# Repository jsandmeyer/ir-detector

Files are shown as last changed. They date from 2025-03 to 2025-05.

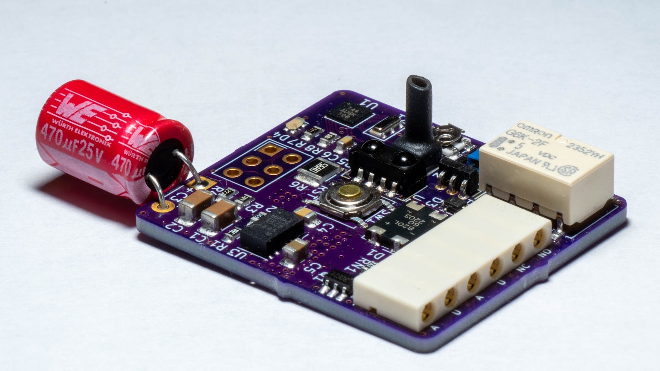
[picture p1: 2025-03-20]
resources/v14_production_model.jpg

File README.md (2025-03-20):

## IR Reflection Detector

This provides resources to help you build an IR detector for use with O-scale model railroad track in order to detect passing trains for operating block signals.

It is designed to be placed beneath the tracks, to allow for the use of more realistic trackside accessories and buildings.

It emits and detects IR at 38KHz (though the frequency can be changed based on part choice).
This prevents background light from affecting function.

The original analog designs utilized a TLC555 CMOS timer.
The timer was unstable through stray capacitance caused by rail operation, and also likely by temperature fluctuations from the power supply.
Small microcontrollers like the ATTINY family are inexpensive, simple to program, and more stable even without an external clock.

The current versions utilize a switching power supply to avoid heat, so the device can be safely placed under track.
The input voltage is 18V RMS AC, which rectifies to 26V DC.
Since only 3-5 volts are needed for the circuit, power dissipation through a linear supply is excessive.

### Design Requirements

1. Must be able to handle 18V RMS AC (or a little more)
2. Must be able to handle rapid shutoff of power
3. Must avoid producing noticeable heat
4. Must fit hidden under track
   1. Shape limits (avoid track supports, power connectors, etc)
   2. Size limits (must not extend past track base, must have a way to feed wires)
   3. Some components must be aligned under a single oblong hole in track base
5. Emitter LED must be shrouded to avoid directly triggering detector
6. Must handle stray capacitance, excessive heat, and some signal interference
7. Must be small to reduce cost, especially when a 4-layer design is used

### Circuit Parts

1. MCU: Responsible for PWM to control the IR emitter, and controlling the relay when a reflection is detected.
2. Switching Power Supply: reduce up to 35VDC input to 3V output for the MCU, IR LED, and relay.
3. IR LED: an emitter running at ~70mA, and 50% duty cycle at 36-56KHz depending on detector part selection.
4. IR Detector: an IC containing both a detector and frequency detection logic, to ensure only correct-frequency light is detected.  36, 38, 40, or 56 KHz.
5. Relay: Controls AC (or DC) current from inputs to a normally-open and normally-closed output.
6. Trimmer: Controls duration of relay after IR is no longer detected.

### Design Versions

Some versions are skipped.
Those were only built on breadboard, or designed and considered non-viable.
Generally, each version is smaller or similar to the previous.

* Version 7: Used TLC556.  Had heat issues from power supply.
* Version 11: Used a switching power supply.  Still had stability issues.
* Version 13: Switched to use an ATTINY84.  Switched to 4-layer board.  Bridge rectifier could not handle rapid shutoff of some transformers.
* Version 14: Larger bridge rectifier.  Production model.  [Image](./resources/v14_production_model.jpg)
* Version 17: Updated layout, components (ATTINY20), and code.  Reduced to 2-layer board.  Manufacturing in process.

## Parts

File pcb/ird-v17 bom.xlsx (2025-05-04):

Ref | Value | SKU | Status | $/1 | $/3 | $/10
C1 | 2.2µF | GCM31CR71H225KA55L |  | $0.33 | $0.99 | $1.98
C2 | 100nF | GCM155R71H104KE02D |  | $0.10 | $0.30 | $0.31
C3 | 1µF | CGA3E1X7R1V105K080AC |  | $0.23 | $0.69 | $1.31
C4 | 10µF | GRM21BR61E106MA73L |  | $0.17 | $0.51 | $0.99
C5 | 100nF | GCM155R71H104KE02D |  | $0.10 | $0.30 | $0.31
C6 | 680µF | 860020575016 |  | $0.61 | $1.83 | $6.01
D1 | -AA+ | CD-HD2006L |  | $0.98 | $2.94 | $7.33
D2 | IR | SFH_4243-Z |  | $0.65 | $1.95 | $4.52
D3 | Diode | 1N4148WS |  | $0.13 | $0.39 | $0.92
D4 | LED | SML-LXFP0603UWW-TR | OPTIONAL | $0.44 | $1.32 | $2.99
J1 | TPI POGO | Atmel 6-pin TPI connector | DNP | $0.00 | $0.00 | $0.00
J2 | Conn 2x6 | 9296006202906 |  | $0.81 | $2.43 | $6.86
K1 | Relay DPDT | G6K-2G-Y-TR DC5 |  | $4.21 | $12.63 | $39.79
Q1 | NPN 10K 10K x2 | MUN5211DW1T1G |  | $0.23 | $0.69 | $1.39
R1 | 10K | RCS040210K0FKED |  | $0.11 | $0.33 | $0.52
R2 | 56R | RCS040256R0FKED |  | $0.12 | $0.36 | $0.58
R3 | 750R | RCS0402750RFKED | OPTIONAL | $0.12 | $0.36 | $0.58
U1 | ATTiny20 | ATTINY20-UUR |  | $1.18 | $3.54 | $11.80
U2 | IR Detector | TSOP75438TT |  | $1.34 | $4.02 | $11.22
U3 | 5V SMPS | TLVM365R1RDNR |  | $2.28 | $6.84 | $16.87
VR1 | 10K | TC42X-2-103E |  | $0.45 | $1.35 | $3.79
PCB | PCB | PCB | PCB | $2.00 | $6.00 | $20.00
Total |  |  |  | $16.59 | $49.77 | $140.07

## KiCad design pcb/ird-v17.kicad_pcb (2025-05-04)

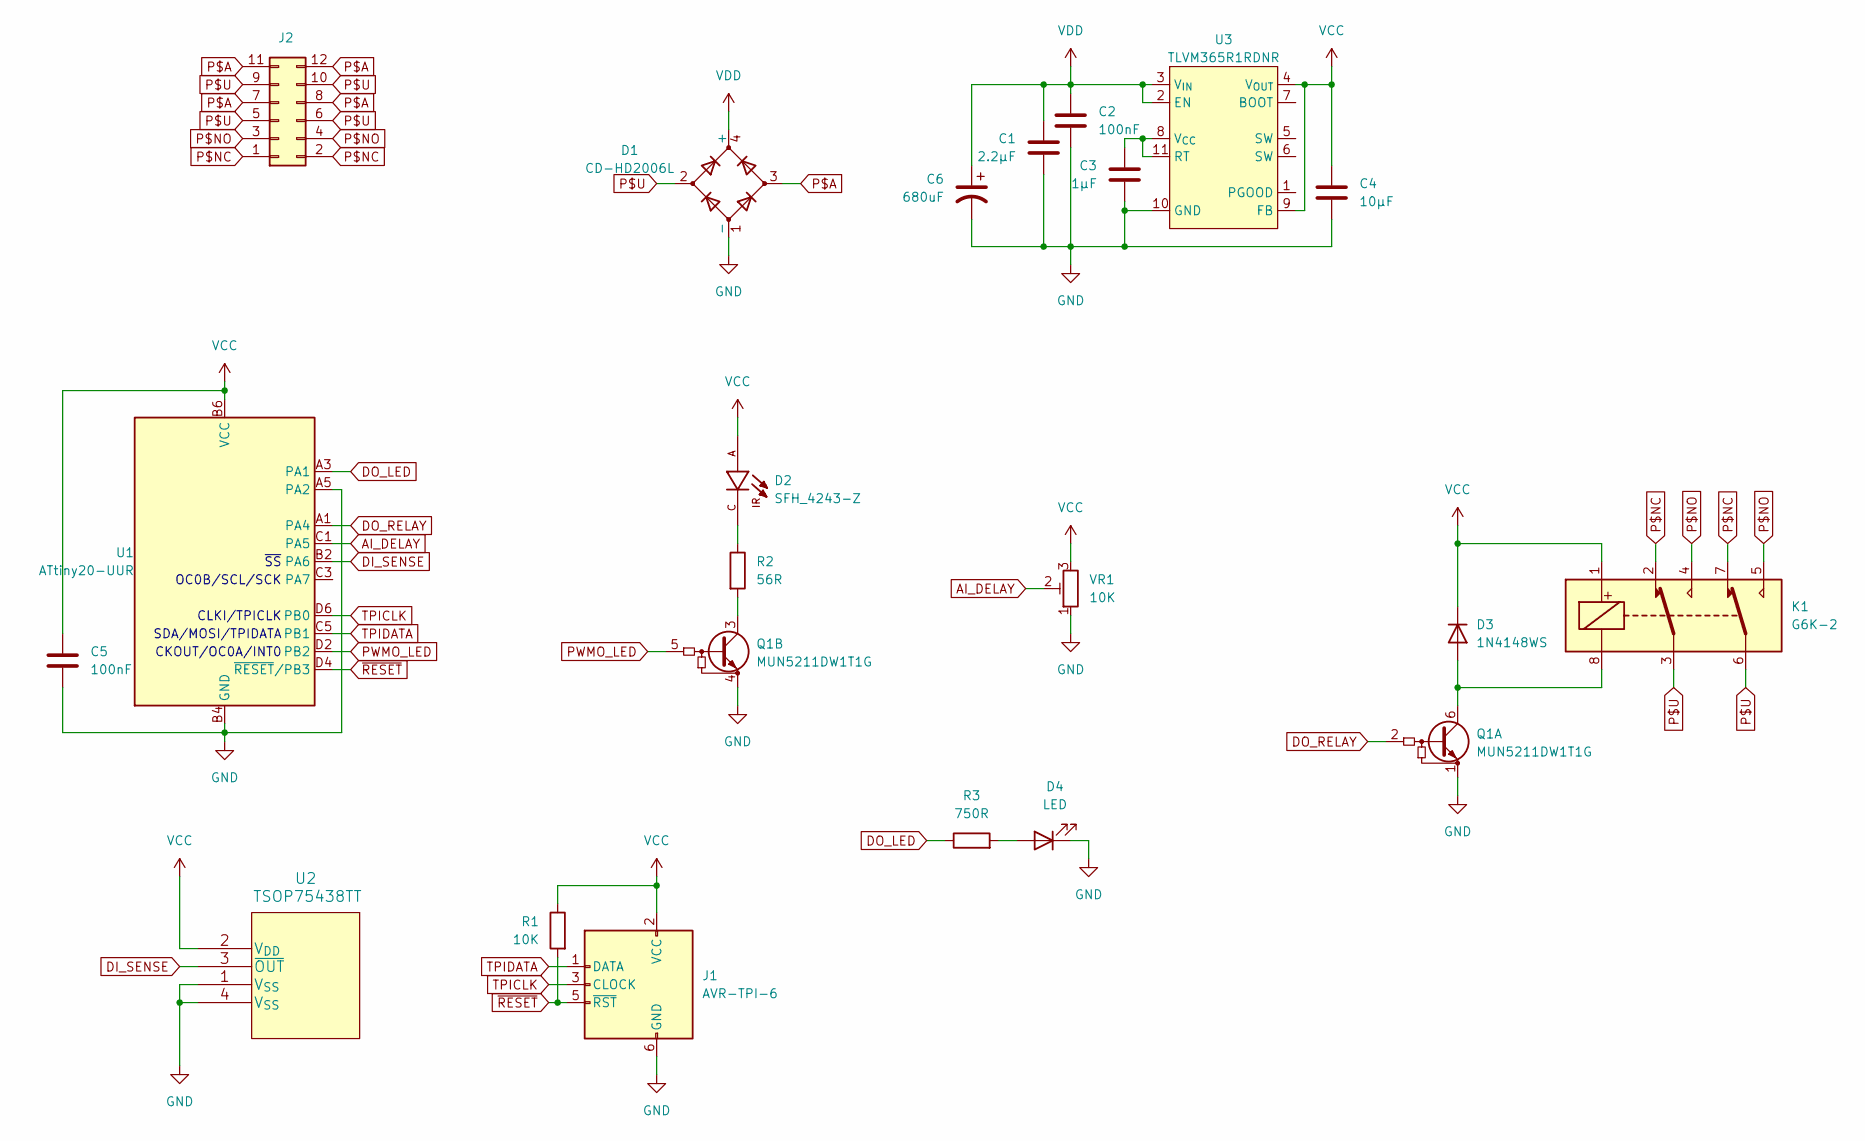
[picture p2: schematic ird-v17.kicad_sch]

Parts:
C1: 2.2µF; C_0805_2012Metric
C2, C5: 100nF; C_0402_1005Metric
C3: 1µF; C_0603_1608Metric
C4: 10µF; C_0805_2012Metric
C6: 680uF; CP_Radial_Long_Sideways_Flip
D1: CD-HD2006L; Diode_Bridge_Bourns_CD-HD2x
D2: SFH_4243-Z; LED_SFH_4243-Z; PARTREV 1.4
D3: 1N4148WS; D_SOD-323
D4: LED; LED_0603_1608Metric
J1: AVR-TPI-6; PinHeader_ISP_POGO
J2: Conn_02x06_Odd_Even; Kyocera_AVX_009296006202906
K1: G6K-2; Relay_DPDT_Omron_G6K-2G-Y
Q1: MUN5211DW1T1G; SOT-363_SC-70-6
R1: 10K; R_0402_1005Metric
R2: 56R; R_0402_1005Metric
R3: 750R; R_0402_1005Metric
U1: ATtiny20-UUR; WLCSP-12_1.403x1.555mm_Layout6x4_P0.4mm_Stagger
U2: TSOP75438TT; TSOP75438WTT
U3: TLVM365R1RDNR; QFN-FCMOD_TI_11C
VR1: 10K; Potentiometer_Bourns_TC42X_Vertical

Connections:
AI_DELAY: U1.C1 (PA5), VR1.2
DI_SENSE: U1.B2 (PA6), U2.3 (~OUT)
DO_LED: R3.1, U1.A3 (PA1)
DO_RELAY: Q1.2 (B1), U1.A1 (PA4)
GND: C1.2, C2.2, C3.2, C4.2, C5.2, C6.2, D1.1 (-), D4.1 (K), J1.6 (GND), Q1.1 (E1), Q1.4 (E2), U1.A5 (PA2), U1.B4 (GND), U2.1 (V_{SS}), U2.4 (V_{SS}), U3.10 (GND), VR1.1
unnamed: D2.C, R2.1
unnamed: D3.2 (A), K1.8, Q1.6 (C1)
unnamed: D4.2 (A), R3.2
unnamed: Q1.3 (C2), R2.2
unnamed: C3.1, U3.8 (V_{CC}), U3.11 (RT)
P$A: D1.3, J2.7, J2.8, J2.11, J2.12
P$NC: J2.1, J2.2, K1.2, K1.7
P$NO: J2.3, J2.4, K1.4, K1.5
P$U: D1.2, J2.5, J2.6, J2.9, J2.10, K1.3, K1.6
PWMO_LED: Q1.5 (B2), U1.D2 (PB2)
TPICLK: J1.3 (CLOCK), U1.D6 (PB0)
TPIDATA: J1.1 (DATA), U1.C5 (PB1)
VCC: C4.1, C5.1, D2.A, D3.1 (K), J1.2 (VCC), K1.1, R1.1, U1.B6 (VCC), U2.2 (V_{DD}), U3.4 (V_{OUT}), U3.9 (FB), VR1.3
VDD: C1.1, C2.1, C6.1, D1.4 (+), U3.2 (EN), U3.3 (V_{IN})
~RESET: J1.5 (~RST), R1.2, U1.D4 (~RESET/PB3)

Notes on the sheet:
CLKI/TPICLK
SDA/MOSI/TPIDATA
CKOUT/OC0A/INT0
~{SS}
OC0B/SCL/SCK

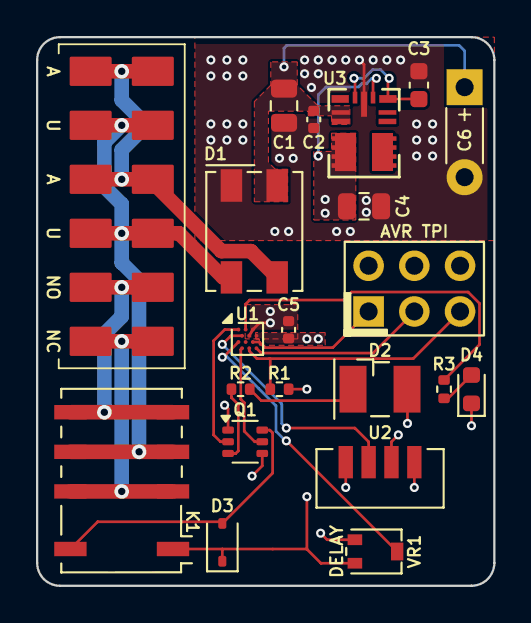
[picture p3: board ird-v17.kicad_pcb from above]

Board: 2 copper layers, 25.4 x 30.5 mm, 21 parts (0 on the bottom side), 20 nets.

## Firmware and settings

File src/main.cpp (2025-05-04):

/*
 * IR Detector V17
 * Send to attiny20 via tpi
 *
 * Created: 2022-07-29 20:26:16
 * Author : John Sandmeyer
 *
 * Optional external defines:
 * DELAY_MAX_S: max delay of relay timer, default 30s
 * IR_HZ: speed of IR LED to match sensor (default 38000L)
 */

#include <avr/io.h>
#include <avr/interrupt.h>
#include <util/delay.h>
#include <avr/sfr_defs.h>
#include "IRManager.h"
#include "RelayManager.h"
#include "ADCManager.h"

static volatile IRManager irManager; // NOSONAR
static volatile RelayManager relayManager; // NOSONAR

int main() {
    // disable prescaler - set CCP to disable configuration change protection
    // enforces a clock source and disables prescaler
    CCP = 0xD8;
    CLKMSR = 0;
    CCP = 0xD8;
    CLKPSR = 0;

    IRManager::configurePWM();
    IRManager::configureInterrupts();

    RelayManager::configurePWM();
    RelayManager::configureInterrupts();
    RelayManager::configureOutputs();

    ADCManager::configureADC();

	// wait 1.5 sec before enabling interrupts
	_delay_ms(1500);
	sei();

    // ReSharper disable once CppDFAEndlessLoop : loop is to keep MCU running while interrupts operate
    while (true) {
		/* loop forever, let interrupts do the work */
	}
}

/**
 * Invoked when something in PORTA is changed
 * Check to see if the state on the pin we care about changed, since it could fire for other reasons
 */
ISR(PCINT0_vect) {
    const auto state = irManager.getIRState();

	if (state == IRManager::State::DETECTED) {
        RelayManager::handleIRDetected();
	} else if (state == IRManager::State::CLEARED) {
	    const auto adcValue = static_cast<unsigned long>(ADCManager::readADC());

#if DEBUG_RELAY_TIMER == 1
	    // in debug mode, IR LED is adjusted based on ADC value for easy testing
	    // use formula HZ = 8MHz / (2 * (1 + OCR0A)) or OCR0A = 4000/KHz - 1
	    // or adcValue = ((4000/KHz) - 1)(1024/255)
	    // adcValue should be between 0 and 1023 (inclusive)
	    // for verification, ADC value 0 -> 4MHz, value 1023 -> 15.686KHz
	    OCR0A = static_cast<uint8_t>(adcValue * 255UL / 1024UL);
	    OCR0B = static_cast<uint8_t>(adcValue * 255UL / 1024UL);
#endif

	    // get the number of ticks based on ADC data, send flag to relay manager
	    const auto ticks = (adcValue * RelayManager::delayMultiplier) / RelayManager::maxADC;
	    relayManager.handleIRCleared(ticks);
	}
}

/**
 * Runs when TIMER1 compare matches
 * Use to decrement relay manager's timer, to turn off the relay eventually
 */
ISR(TIM1_COMPA_vect) {
    relayManager.tick();
}

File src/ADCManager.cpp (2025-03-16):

#include "ADCManager.h"

void ADCManager::configureADC() {
    // Pin A1 has the variable resistor
    DDRA &= ~_BV(adcPin);

    // Right half of ADMUX selects which channel to read, leave left half alone
    ADMUX &= 0xF0;
    ADMUX |= adcChannel; // select channel 1

    // Disable digital input on ADC1
    DIDR0 = _BV(ADC1D);

    // Enable the ADC
    ADCSRA |= _BV(ADEN);
    ADCSRA |= _BV(ADSC);
}

uint16_t ADCManager::readADC() {
    ADMUX &= 0xF0;
    ADMUX |= adcChannel;
    ADCSRA |= _BV(ADSC);

    while (ADCSRA & _BV(ADSC)) {
        /* wait for ADSC to return to 0 */
    }

    // read ADCH last, once you do, ADCL disappears
    return (static_cast<uint16_t>(ADCL) + (static_cast<uint16_t>(ADCH) << 8u)) & 0x03FF;
}

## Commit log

2025-03-15 Rearrange pins
    [ird-v17.kicad_pcb, ird-v17.kicad_sch]
2025-03-16 PCB project update
2025-03-20 PCB update
    [ird-v17.kicad_pcb, ird-v17.kicad_sch]
2025-03-20 Update BOM
    [ird-v17 bom.xlsx, ird-v17.kicad_sch]
2025-05-04 Update to use 5V for consistent ATTINY20 programming
    [ird-v17 bom.xlsx, ird-v17.kicad_pcb, ird-v17.kicad_sch]
